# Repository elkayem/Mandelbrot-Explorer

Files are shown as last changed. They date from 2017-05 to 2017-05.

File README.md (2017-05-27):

# Mandelbrot-Explorer

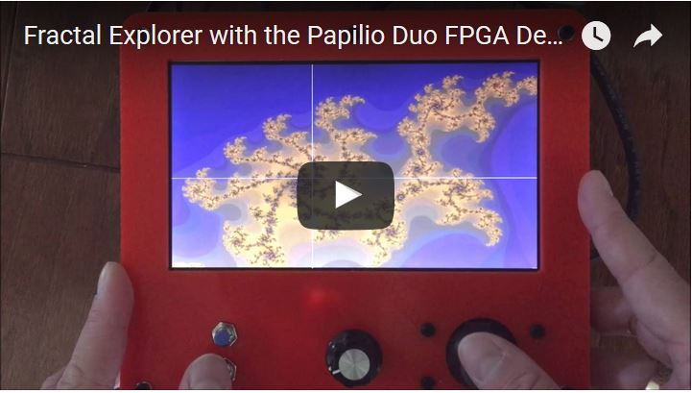
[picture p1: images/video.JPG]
Mandelbrot Explorer (https://www.youtube.com/watch?v=OqxMnT_Ruuk)
 

(Click on image above for link to YouTube video)

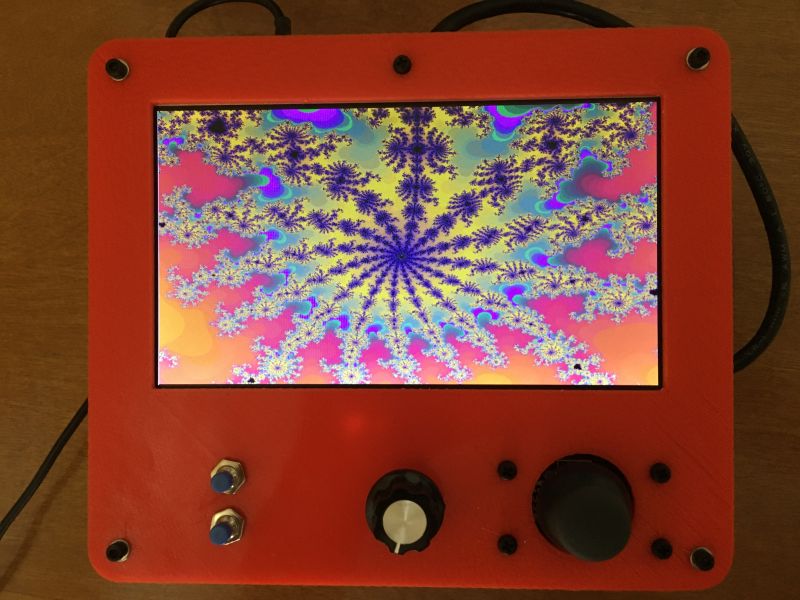
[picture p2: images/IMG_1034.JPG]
Fractal1
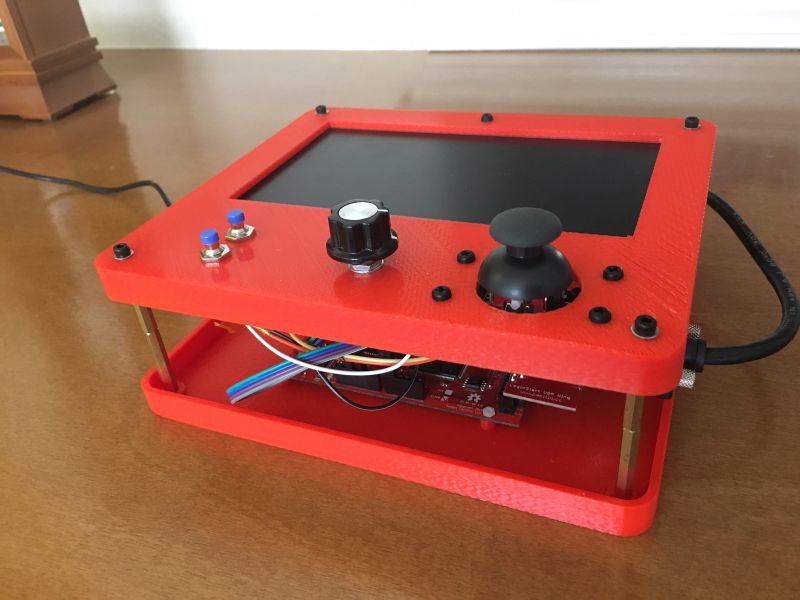
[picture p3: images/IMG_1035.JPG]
Fractal2
 

This is an FPGA-based Mandelbrot Set explorer.  I used the Papilio Duo board from Gadget Factory, which includes a Xilinx Spartan 6 LX9 FPGA, an ATmega32U4 microcontroller (the same one used in the Arduino Leonardo), and 512 MB SRAM.  A few notable features of this project:

* I used the Atmega32U4 to process the analog joystick, buttons, and rotary encoder to set the cursor position, zoom, and color map.  This information is sent over to the FPGA via an SPI interface.
* The FPGA runs the 800x600 pixel fractal calculations at 200 MHz using the onboard DSP48s.
* The fractals are saved to SRAM, with each pixel stored as a 1 byte word.
* A set of selectable 12-bit color maps are stored using the FPGA BRAM.  I currently have over a dozen, and am planning on adding more color maps.
* An 800x600 pixel SVGA controller on the FPGA is used to send a 12-bit color image to the LCD.  I used the snap-off VGA wing that came with Gadget Factory’s LogicStart Shield.  The LCD was an inexpensive 7” screen purchased off eBay, typically used for Raspberry Pi projects.
* The case for this design was 3D printed, and custom designed just for this project.

I embarked on this project to learn how to program in VHDL.  The Papilio boards are a great and inexpensive way to learn about FPGA design.  The one I used was $88, with all the necessary software tools free from Xilinx.  This project was inspired by a similar project by Mike Field (aka Hamster), who also has a great self-paced tutorial on learning VHDL using a Spartan FPGA.  Although my project was not a copy of Mike's Mandelbrot projects, I did learn quite a bit from his project and tutorials on how to pipeline an algorithm, implement a finite state machine, and many other bread and butter skills needed for FPGA design.  In fact, you can find Mike's pipelining entities used in my VHDL code.

Please feel free to use the VHDL, Arduino code, and even print yourself a 3D printed case for your own Mandelbrot explorer project.  I do have one word of caution: *Please don't try to learn VHDL from my code!*   As a self-taught novice, I'm sure I've implemented all sorts of bad coding practices that would have been weeded out in any undergraduate course.  Instead, head over to (http://hamsterworks.co.nz/mediawiki/index.php/FPGA_Projects) for a dizzying list of FPGA projects done the right way.  

You can also find the 3D printed case design over at: (https://www.thingiverse.com/thing:1655662)

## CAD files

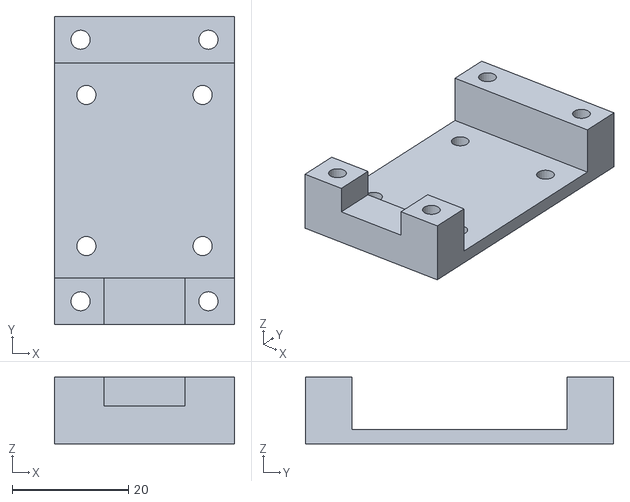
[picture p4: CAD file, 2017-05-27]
3D Printed Case/JoystickBase.stl
31.0 x 53.0 x 11.5

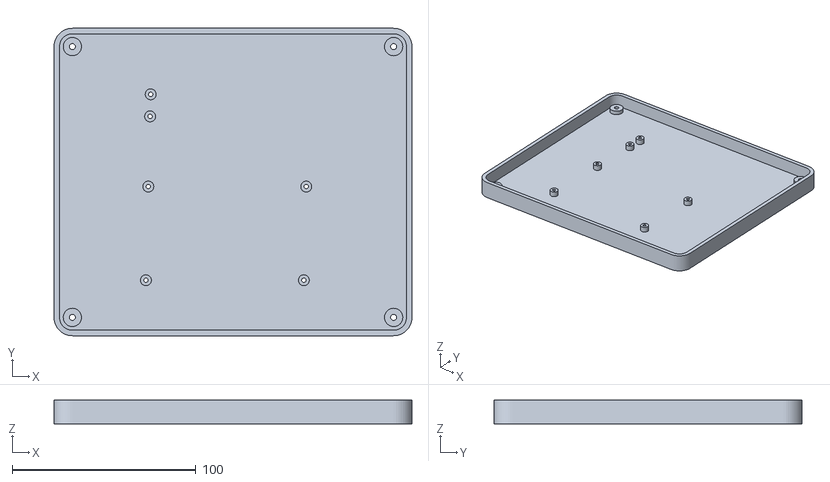
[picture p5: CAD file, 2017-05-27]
3D Printed Case/Papilio_LCD_Case_bottom.stl
195.0 x 167.5 x 13.0

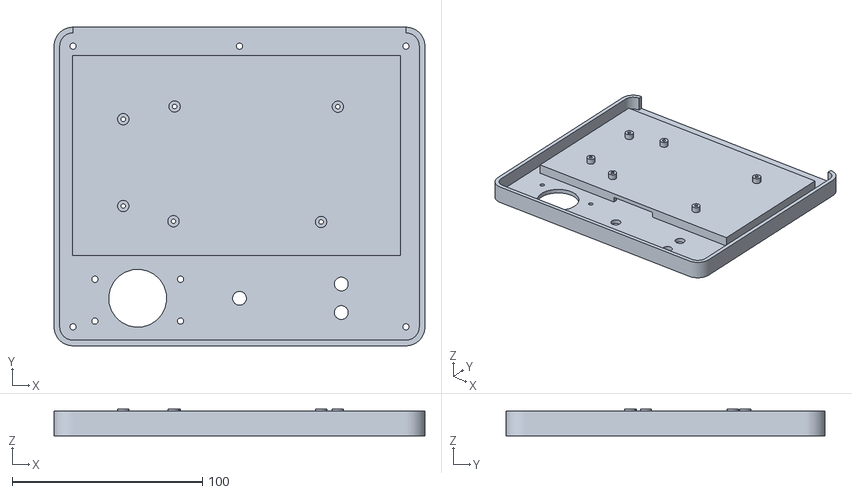
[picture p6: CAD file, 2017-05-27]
3D Printed Case/Papilio_LCD_Case_top.stl
195.0 x 167.5 x 14.0

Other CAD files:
3D Printed Case/JoystickMount.skp
3D Printed Case/Papilio_LCD_Case.skp

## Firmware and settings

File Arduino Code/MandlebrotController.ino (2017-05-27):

#include <SPI.h>
#include "Switch.h"

//#define SERIAL_OUT

const int upDownPin = A0;   
const int leftRightPin = A1; 
const int slaveSelectPin = 10;
const int zoomInButtonPin = 3;
const int zoomOutButtonPin = 4;
const int refreshButtonPin = 2;
const int encoderPinA = 0;
const int encoderPinB = 1;

Switch zoomInButton   = Switch(zoomInButtonPin);
Switch zoomOutButton  = Switch(zoomOutButtonPin);
Switch refreshButton  = Switch(refreshButtonPin);

#define UPDATE_PX_COMMAND 0x01
#define UPDATE_AREA_COMMAND 0x02

// Fractal math done in fixed-point, with LSB = 2^(-33)
int64_t cr = -17179869184;  // Frame left edge, RW value = -2.0 = cr/LSB
int64_t ci = -10066329600;  // Frame bottom edge, RW value = -1.17 = ci/LSB
int64_t dc = 33554432; // Frame pixel size, RW value = 0.0039 = dc/LSB, dc = 2^25
const int64_t dc_max = 33554432;  

const float maxRate = 300; // 300 pixels per second
const int HD = 800, VD = 600; // 800x600 pixels
const int deadzone = 10; 
const int JS_UpdatePeriod = 50; // msec
const float rateSF = maxRate * (0.001 * (float)JS_UpdatePeriod);

const int edgeUpdatePeriod = 250; // msec
const float edgeScanRate = 150 * (0.001 * (float)edgeUpdatePeriod);  // 150 pix/sec

unsigned char current_color_palatte = 0;
const int max_palattes = 13;

float cursorX = 400, cursorY = 300;  // Start at center
float cursorXprev, cursorYprev;

unsigned long int serial_timer, JS_UpdateTimer, edgeTimer, cursorTimer;
const int cursorTimeout = 5000;

void setup() {
  Serial.begin(9600);
  pinMode(slaveSelectPin, OUTPUT);
  pinMode(encoderPinA, INPUT_PULLUP);
  pinMode(encoderPinB, INPUT_PULLUP);
  
  SPI.begin(); 
  SPI.beginTransaction (SPISettings (2000000, MSBFIRST, SPI_MODE0));  // 2 MHz clock, MSB first, mode 0
  serial_timer = millis();
}

void loop() {
  char str[100];
  static float JSx, JSy;
  int upDown, leftRight, i;  
  int64_t cursorX_fp, cursorY_fp;
  
  if (millis() - JS_UpdateTimer > JS_UpdatePeriod) {
    upDown = analogRead(upDownPin);
    leftRight = analogRead(leftRightPin);
    
    if (((leftRight - deadzone) > 512) || (leftRight + deadzone) < 512) {
     JSx = (float)(leftRight-512)/512.0f;  // Range -1 to 1
     cursorX += abs(JSx)*JSx*rateSF;
     if (cursorX > HD-1) cursorX = HD-1;
     else if (cursorX < 0) cursorX = 0;
    }
    else JSx = 0;
    
    if (((upDown- deadzone) > 512) || (upDown + deadzone) < 512) {
     JSy = (float)(upDown-512)/512.0f;
     cursorY += abs(JSy)*JSy*rateSF;  
     if (cursorY > VD-1) cursorY = VD-1;
     else if (cursorY < 0) cursorY = 0;
    }
    else JSy = 0;
    
    if ((cursorX != cursorXprev) || (cursorY != cursorYprev)) {  // reset cursor timeout counter
      cursorTimer = millis();
    }
    cursorXprev = cursorX; cursorYprev = cursorY;
    
    digitalWrite(slaveSelectPin, LOW);
    SPI.transfer(UPDATE_PX_COMMAND);
    if (millis() - cursorTimer < cursorTimeout) {
      SPI.transfer16((int)cursorX);
      SPI.transfer16((int)cursorY);
    }
    else { // Make cursor disappear (set to HD,VD) if cursor hasn't moved for more than timeout period
      SPI.transfer16(HD);
      SPI.transfer16(0);
    }      
    SPI.transfer(current_color_palatte);
    for (i=0; i<10; i++) SPI.transfer(0x00);  // Transfer 10 more empty bytes    
    digitalWrite(slaveSelectPin, HIGH);
    
    JS_UpdateTimer = millis();
  }
  
  zoomInButton.poll();
  zoomOutButton.poll();
  refreshButton.poll();
  
  if (zoomInButton.pushed()) {// zoom in
      cursorX_fp = cr + dc*cursorX;
      cursorY_fp = ci + dc*cursorY;
      if (dc != 1) dc >>= 1;
      cr = cursorX_fp - 400*dc;
      ci = cursorY_fp - 300*dc;
      sendUpdate120();
      cursorX = 400; cursorY = 300;  // Recenter cursor
  }
  else if (zoomOutButton.pushed()) {// zoom out
      cursorX_fp = cr + dc*cursorX;
      cursorY_fp = ci + dc*cursorY;
      if (dc < dc_max) dc <<= 1;
      cr = cursorX_fp - 400*dc;
      ci = cursorY_fp - 300*dc;
      sendUpdate120();
      cursorX = 400; cursorY = 300;  // Recenter cursor
  } else if (refreshButton.pushed()) {// refresh
      sendUpdate120();
  }
  current_color_palatte = updateEncoderPos();
  
  if (millis() - edgeTimer > edgeUpdatePeriod) {
    if (cursorX == HD-1 && JSx > 0.25) {
      cr += dc * edgeScanRate;
      sendUpdate120();
    }
    else if (cursorX == 0 && JSx < -0.25) {
      cr -= dc * edgeScanRate;
      sendUpdate120();
    }
    if (cursorY == VD-1 && JSy > 0.25) {
      ci += dc * edgeScanRate;
      sendUpdate120();
    }
    else if (cursorY == 0 & JSy < -0.25) {
      ci -= dc * edgeScanRate;
      sendUpdate120();
    }
    edgeTimer = millis();
  } 
       
#ifdef SERIAL_OUT

    
  if ((millis() - serial_timer) > 100) {
    Serial.print(digitalRead(encoderPinA));
    Serial.print(" ");
    Serial.print(digitalRead(encoderPinB));
    Serial.print(" ");
    Serial.println(current_color_palatte);
    
   // sprintf(str,"Up/Down = %d, Left/Right = %d", upDown, leftRight);
   // Serial.println(str);
   // sprintf(str,"X Pixel = %d, Y Pixel = %d", (int)cursorX, (int)cursorY);
    
   // Serial.println(str);
    serial_timer = millis();
  }
#endif

}

void sendUpdate120() {
  digitalWrite(slaveSelectPin, LOW);
  SPI.transfer(UPDATE_AREA_COMMAND);
  sendUpdate40(cr);
  sendUpdate40(ci);
  sendUpdate40(dc);
  digitalWrite(slaveSelectPin, HIGH);
}


void sendUpdate40(int64_t num) {
    int i;
    unsigned char byteArray[5];
    for (i = 0; i < 5; i++) {
      byteArray[i] = num & 0xFF;
      num >>= 8;
    }
    for (i=4; i>= 0; i--){  // Send MSB first
      SPI.transfer(byteArray[i]);
      //print_binary((int)byteArray[i],8);
      //Serial.print(" "); 
    }  
    //Serial.println();
}


int updateEncoderPos() {
    static int encoderA, encoderB, encoderA_prev;   

    static int encoderPos;

    encoderA = digitalRead(encoderPinA); 
    encoderB = digitalRead(encoderPinB);
 
    if((!encoderA) && (encoderA_prev)){ // A has gone from high to low 
      encoderB ? encoderPos++ : encoderPos--;         
    }
    encoderA_prev = encoderA;     
    // Wrap logic
    if (encoderPos >  max_palattes-1) encoderPos = 0;
    else if (encoderPos < 0) encoderPos = max_palattes-1;  

   return encoderPos;
}


void print_binary(int v, int num_places)
{
    int mask=0, n;

    for (n=1; n<=num_places; n++)
    {
        mask = (mask << 1) | 0x0001;
    }
    v = v & mask;  // truncate v to specified number of places

    while(num_places)
    {
        if (v & (0x0001 << num_places-1))
        {
             Serial.print("1");
        }
        else
        {
             Serial.print("0");
        }

        --num_places;
        if(((num_places%4) == 0) && (num_places != 0))
        {
            //Serial.print(" ");
        }
    }
}
